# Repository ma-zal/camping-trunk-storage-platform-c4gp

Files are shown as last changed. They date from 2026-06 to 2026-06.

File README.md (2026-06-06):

# Držáky dřevěného profilu pro vestavbu kempovací poličky do automobilu

3D tisknutelné držáky pro upevnění dřevěného profilu, na který se připevní polička.
Držáky jsou navrženy pro snadné nasazení a zajištění proti vysunutí, přičemž využívají existující otvory a oka v zavazadlovém prostoru automobilu.

Pro vůz: Citroen C4 Grand Picasso 2. gen (od 2013)
Jazyk zdrojových dat 3D modelu: OpenSCAD

Rozměry a odvozené hodnoty jsou parametry na začátku každého `.scad` souboru. Sem patří jen účel a záměry, které z kódu nejsou na první pohled zřejmé.

## Přední držák

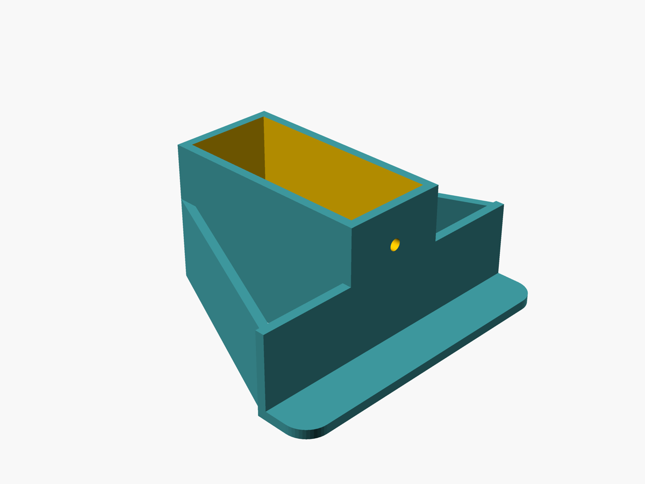
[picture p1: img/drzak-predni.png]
Přední držák


Soubor: `vestavba-drzak-predni.scad`

Účel: nasouvací držák na vodorovný dřevěný profil (vyšší stranou nahoru). Jazýček zapadne do vodorovného úzkém otvoru v automobilu (kterým se vysouvá bezpečnostní pás) a zajistí profil proti vysunutí.

Potřebný dřevěný trám: profil **19 × 43 mm** (užší strana 19 mm, vyšší strana 43 mm nahoru).

Hlavní prvky a záměry:
- Průchozí obdélníkový tunel, otevřený na obou koncích (profil jím prochází).
- Jazýček (háček) na horní straně míří ven od těla a dolů do otvoru. Zaoblený je jen na svých dvou vnějších hranách, strana u těla zůstává ostrá.
- Horní základna rozšiřuje horní plochu do stran a drží profil na středu (proti překlápění). Je zapuštěná do horní stěny tunelu, aby nahoře nevznikala dvojitá tloušťka materiálu.
- Boční výztuhy: jen jedna šikmá deska na každé straně (úhlopříčka od hrany základny k patě tunelu), jejíž vnější hrana lícuje se základnou a nepřečnívá. Záměrně žádný plný ani dutý trojúhelník a žádné členy podél základny či tunelu.
- Volitelný otvor na šroubek skrz horní stěnu tunelu.

`is_poc = true` přepíná na mělčí zkušební variantu (pro rychlejší vytištění).

## Zadní díl - přítlačná podložka

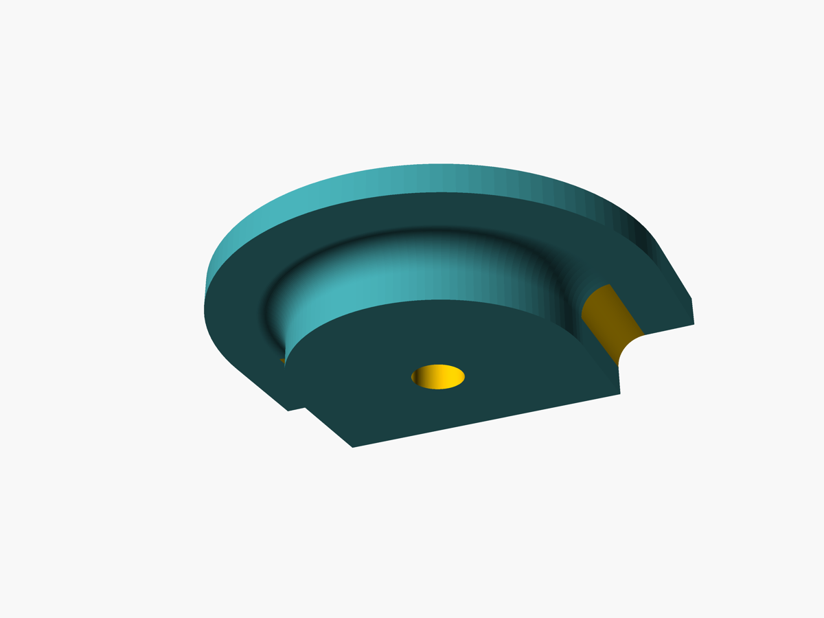
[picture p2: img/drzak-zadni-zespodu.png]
Zadní díl – pohled zespodu na lůžko oka


*Pohled zespodu – na spodní (dosedací) straně je vidět konkávní lůžko (drážka) kopírující prut oka ve tvaru „U".*

Soubor: `vestavba-drzak-zadni.scad`

Princip: Zadní trám leží na okách umístěných na bočních stěnách zavazadlového prostoru. Oka se otočí do vodorovné polohy. Přítlačná podložka se položí na oko a zajistí se šroubkem, který ji přitahuje dolů. Tím přitlačuje oko k trámu a zároveň brání posunutí oka po trámu. Jde tedy o tvarovanou podložku usazenou na oku, jejímž úkolem je oko zafixovat – přitlačit i zaaretovat.

Hlavní prvky a záměry:
- Tvar kopíruje oko ve tvaru „U" (půlkruh + dvě rovné nohy): podložka je z jedné strany kulatá, zbytek rovný.
- Tělo je zespodu tlustý blok se svislou stěnou, nahoře tenký širší lem.
- Lůžko pro prut oka je na spodní straně zaobleno.
- Průchozí otvor pro šroub ve středu, bez zapuštění (kvůli pevnosti).

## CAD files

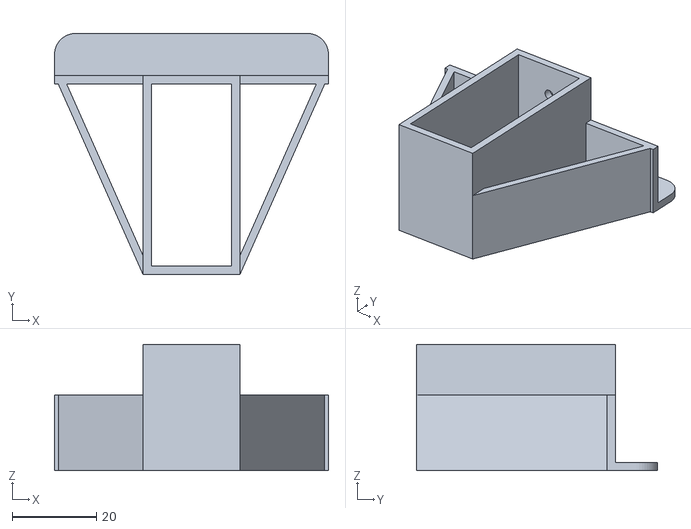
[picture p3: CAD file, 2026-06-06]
vestavba-drzak-predni.stl
65.0 x 57.2 x 30.0

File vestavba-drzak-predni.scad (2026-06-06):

// =====================================================================
//  Nasouvací držák na dřevěný profil 19 x 43 mm
//  ------------------------------------------------------------------
//  Souřadný systém:
//    X = šířka (vodorovně napříč), model je vycentrovaný na X = 0
//    Y = výška (svisle), Y = 0 je dole, profil stojí vyšší stranou nahoru
//    Z = směr nasunutí profilu (tunel je v ose Z průchozí)
// =====================================================================

is_poc = false; // Mene hlubsi varianta, na vyzkouseni

// ---------- Parametry profilu a nasunutí ----------
inner_x = 19;   // vnitřní šířka tunelu (kratší strana profilu + vůle)
inner_y = 43.2;   // vnitřní výška tunelu (delší strana profilu + vůle)
insert_len = is_poc ? 15 : 30;  // délka nasouvací části (hloubka tunelu v ose Z)
wall = 2;         // tloušťka pláště

// ---------- Parametry základny a výztuh ----------
base_w = 65;      // celková šířka základny (shodná se šířkou jazýčku)
base_t = wall;    // tloušťka horní desky základny (zapuštěná do horní stěny tunelu)
rib_depth = is_poc ? 15 : 18;   // vyska bočních výztuh v ose Z (není potřeba celých 20)
rib_wall = wall;  // tloušťka stěny (rámu) duté výztuhy

// ---------- Parametry jazýčku (háčku) ----------
tongue_w = base_w;       // šířka jazýčku
tongue_thick = 2;    // tloušťka stěny jazýčku (v ose Z)
tongue_depth = 10;   // hloubka jazýčku (jak daleko směřuje dolů, osa Y)
tongue_round = 5;  // poloměr zaoblení koncových hran jazýčku

// ---------- Odvozené vnější rozměry ----------
outer_x = inner_x + 2 * wall;   // 25.6 mm
outer_y = inner_y + 2 * wall;   // 49.6 mm

// Jemnost zaoblení
$fn = 48;

// ---------- Výchozí pohled kamery (aby model nebyl mimo záběr) ----------
// Model je v ose Y posunutý nahoru (Y ≈ 0–53), proto kamera míří na jeho
// střed, ne na počátek [0,0,0].
$vpt = [0, 25, 10];     // bod, na který se kamera dívá (střed modelu)
$vpr = [60, 0, 135];    // rotace pohledu (sklon a natočení)
$vpd = 200;            // vzdálenost kamery (zoom)

// =====================================================================
//  Hlavní sestava
// =====================================================================
module drzak() {
    difference() {
        union() {
            // Nasouvací tunel (s průchozím otvorem)
            insert_tunnel();

            // Horní základna + boční výztuhy + jazýček
            top_base();
            side_ribs();
            tongue();
        }

        // Otvor na šroubek v horní (kratší) stěně tunelu
        if (!is_poc) { // pro zkoušku není potřeba, navíc by se špatně vrtalo
            screw_hole();
        }
    }
}

// ---------------------------------------------------------------------
//  Otvor na šroubek – svislý (osa Y) skrz horní stěnu tunelu na straně
//  jazýčku. Vystředěný na X = 0, v ose Z přibližně 10 mm od zadní hrany
//  tunelu (Z = 20). Průměr 2.5 mm.
// ---------------------------------------------------------------------
module screw_hole() {
    screw_d = 2.5;
    screw_z = insert_len - 8;          // poloha v ose Z (hloubka nasunutí)

    translate([0, outer_y + 0.1, screw_z])
        rotate([90, 0, 0])     // válec z osy Z do osy Y (shora dolů)
            cylinder(h = 2 * wall + 0.2, d = screw_d);
}

// ---------------------------------------------------------------------
//  Nasouvací tunel – obdélníkový průchozí tunel otevřený na obou stranách
// ---------------------------------------------------------------------
module insert_tunnel() {
    difference() {
        // Vnější těleso, vycentrované na X = 0
        translate([-outer_x / 2, 0, 0])
            cube([outer_x, outer_y, insert_len]);

        // Vnitřní průchozí otvor (přesah 0.1 na obou koncích kvůli čistému řezu)
        translate([-inner_x / 2, wall, -0.1])
            cube([inner_x, inner_y, insert_len + 0.2]);
    }
}

// ---------------------------------------------------------------------
//  Horní základna – plochá deska 60 mm široká přes horní stranu tunelu.
//  Je zapuštěná do horní stěny tunelu (horní plocha v rovině outer_y),
//  takže nad tunelem nevzniká dvojitá tloušťka – přes šířku tunelu se
//  jen překryje s jeho stěnou, navíc rozšiřuje horní plochu do stran.
// ---------------------------------------------------------------------
module top_base() {
    translate([-base_w / 2, outer_y - base_t, 0])
        cube([base_w, base_t, rib_depth]);
}

// ---------------------------------------------------------------------
//  Boční výztuhy – jedna šikmá deska (úhlopříčka původního trojúhelníku)
//  napříč od hrany základny dolů k patě tunelu. Členy podél základny ani
//  podél tunelu nejsou potřeba. Vnější hrana desky lícuje s úhlopříčkou
//  (roh základny → pata tunelu), tloušťka jde dovnitř k tunelu, takže
//  deska nepřečnívá za základnu. Tloušťka rib_wall, hloubka rib_depth.
// ---------------------------------------------------------------------
module side_ribs() {
    p_top = [base_w / 2,  outer_y];   // horní vnější roh (hrana základny)
    p_bot = [outer_x / 2, 0];         // dolní vnější roh (pata tunelu)

    for (mx = [1, -1]) {              // pravá (+X) a levá (-X) strana
        scale([mx, 1, 1])
        linear_extrude(height = rib_depth)
            polygon(points = [
                p_top,                  // horní vnější (roh základny)
                p_bot,                  // dolní vnější (pata tunelu)
                p_bot - [rib_wall, 0],  // dolní vnitřní (k tunelu)
                p_top - [rib_wall, 0],  // horní vnitřní
            ]);
    }
}

// ---------------------------------------------------------------------
//  Jazýček (háček) – visí z předního přesahu základny směrem dolů,
//  ven od modelu (mimo těleso tunelu). Šířka 60, tloušťka stěny 4,
//  hloubka 10. Zaoblené jsou koncové (boční) hrany, ne podélné.
//  Zapadne do vodorovného otvoru a zajistí profil proti vysunutí.
// ---------------------------------------------------------------------
module tongue() {
    // Jazýček vychází z horní plochy (rovina outer_y)
    y_bottom = outer_y;

    // Profil leží v rovině šířka (X) × hloubka (Y) a vytlačí se v ose Z
    // (tloušťka). Tím se zaoblí koncové hrany běžící napříč tloušťkou.
    translate([0, y_bottom, 0])
        linear_extrude(height = tongue_thick)
            tongue_profile();
}

// 2D profil jazýčku v rovině (X = šířka, Y = hloubka).
// Zaoblené jsou jen dva vnější rohy (hrany mířící ven, y = d);
// strana přiléhající k držáku (y = 0) zůstává ostrá.
module tongue_profile() {
    w = tongue_w;
    d = tongue_depth;
    r = tongue_round;

    hull() {
        // tělo s ostrou hranou u držáku
        translate([-w / 2, 0]) square([w, d - r]);
        // zaoblené vnější rohy
        translate([-w / 2 + r, d - r]) circle(r = r);
        translate([ w / 2 - r, d - r]) circle(r = r);
    }
}

// =====================================================================
//  Render
// =====================================================================
drzak();

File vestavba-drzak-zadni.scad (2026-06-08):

// =====================================================================
//  Zadní držák – kruhová podložka na oko (přitlačení oka k trámu)
//  ------------------------------------------------------------------
//  Princip (viz README): zadní trám leží na okách na bočních stěnách
//  kufru. Tato podložka se položí na oko a přišroubuje se šroubem skrz
//  střed. Tím přitlačí prut oka k trámu a zároveň brání jeho posuvu –
//  prut oka sedí v lůžku na spodní straně podložky.
//
//  Tvar oka je U (půlkruh + dvě rovné nohy), proto lůžko kopíruje U
//  a samotná podložka je „půl kulatá, zbytek rovný". Tělo je tvořené
//  zespodu: tlustý blok se svislou stěnou + nahoře tenký širší lem.
//  Lůžko prutu NENÍ odebraná drážka – je to konkávní 90° zaoblení (R3)
//  PŘIDANÉ do rohu (stěna ↔ spodek lemu). Stěna pod lůžkem je proto
//  svislá a u dna ostrá, žádný obloukový převis.
//
//  Souřadný systém:
//    Z = tloušťka podložky, Z = 0 je dolní (dosedací) plocha
//    Lůžko pro prut je při spodní ploše (prut sedí zdola, vně stěny)
//    U se otevírá ve směru +Y, kulatá část je na straně -Y, střed na [0,0]
// =====================================================================

// ---------- Hlavní rozměry podložky ----------
thickness       = 9;    // celková tloušťka plného bloku, vcetne tloustky rozsirene casti.
shelf_thickness = 3;    // tloušťka rozsirene casti (lem za drážkou)

// ---------- Parametry oka a jeho drážky ----------
eye_rod_d   = 6;    // průměr prutu oka ("6mm OKO")
eye_pitch_inner_d = 29.4; // průměr vnitřní části U – osa prutu
leg_len     = 8;   // délka rovných nohou U (jak daleko pokračují rovně). Max 15mm.

eye_pitch_d = eye_pitch_inner_d + eye_rod_d;   // průměr kulaté části U – osa prutu

// ---------- Šířky lemu ----------
inner_margin = 0;   // jemný posun svislé stěny (0 = přesně na vnitřní tečně prutu)

// ---------- Otvor na šroub ----------
screw_d     = 5.2;    // průchozí otvor pro šroub skrz střed
screw_offset = 10;  // Posun otvoru oproti středu víc ke špičce

// ---------- Odvozené hodnoty ----------
groove_r   = eye_rod_d / 2;          // poloměr lůžka = 3 mm (rádius z nákresu)
pitch_r    = eye_pitch_d / 2;        // poloměr osy prutu oka = 18 mm
full_r     = pitch_r - groove_r + inner_margin;  // svislá stěna na vnitřní tečně prutu
outer_r    = 46 / 2;             // vnější okraj lemu (polomer od stredu osy)
corner_z   = thickness - shelf_thickness;        // výška spodku lemu = výška rohu (lůžka)

eps = 0.01; // malý posun pro zajištění správného pořadí operací (rozdíl mezi "vnitřní" a "vnější" částí)

// Jemnost zaoblení
$fn = 128;

// ---------- Výchozí pohled kamery ----------
$vpt = [0, 8, 3];
$vpr = [110, 0, 25];
$vpd = 160;

// =====================================================================
//  Hlavní sestava
// =====================================================================
module podlozka() {
    difference() {
        union() {
            // tenký horní lem (širší), na opačné straně než lůžko
            translate([0, 0, corner_z])
                ushape_slab(outer_r, shelf_thickness, leg_len);
            // tlustý blok se svislou stěnou (vnitřní část)
            ushape_slab(full_r, thickness, leg_len);
            // aditivní zaoblené lůžko prutu v rohu (U: oblouk + nohy)
            eye_fillet();
        }
        screw_hole();       // průchozí otvor pro šroub
    }
}

// ---------------------------------------------------------------------
//  Tvar „U" jako plný blok dané tloušťky: půlkruh (poloměr r) na straně
//  -Y + obdélníková část pokračující rovně do +Y o délce L.
// ---------------------------------------------------------------------
module ushape_slab(r, t, L) {
    union() {
        // kulatá půlka (Y <= 0)
        intersection() {
            cylinder(r = r, h = t);
            translate([-r - 1, -2 * r - 1, -1])
                cube([2 * r + 2, 2 * r + 1, t + 2]);
        }
        // rovná část (Y = 0 .. L)
        translate([-r, 0, 0]) cube([2 * r, L, t]);
    }
}

// ---------------------------------------------------------------------
//  Lůžko prutu oka – kopíruje U: konkávní 90° zaoblení (R = groove_r)
//  PŘIDANÉ do rohu, kde se svislá stěna tlustého bloku (poloměr full_r)
//  potkává se spodkem horního lemu (výška corner_z). Prut sedí vně té
//  stěny, spodkem v rovině Z = 0; zaoblení vystředěné na osu prutu tvoří
//  jeho lůžko. Stěna pod lůžkem je svislá a u dna ostrá (nic se neodebírá).
// ---------------------------------------------------------------------
module eye_fillet() {
    // kulatá půlka lůžka (Y <= 0)
    rotate([0, 0, 180])
        rotate_extrude(angle = 180)
            fillet_profile();

    // rovné nohy podél obou stran U
    for (mx = [1, -1])
        scale([mx, 1, 1]) fillet_leg();
}

// 2D profil zaoblení rohu (x = radiála, y = výška): čtverec R×R v rohu
// mínus kružnice R vystředěná na osu prutu → konkávní čtvrtkruhové lůžko.
module fillet_profile() {
    difference() {
        // levá hrana posunutá o eps do středu (−x) → překryv s válcovou stěnou
        // (jinak se profil stěny jen tečně dotýká = čára nulové tloušťky)
        translate([full_r - eps, corner_z - groove_r]) square([groove_r + eps, groove_r]);
        translate([full_r + groove_r, corner_z - groove_r]) circle(r = groove_r);
    }
}

// 3D ekvivalent profilu pro rovnou nohu (+X strana): kvádr v rohu mínus
// válec (osa podél Y) = vytlačený fillet_profile. Přesah 0.1 na obou koncích.
module fillet_leg() {
    difference() {
        translate([full_r, -eps, corner_z - groove_r])
            cube([groove_r, leg_len + 2 * eps, groove_r]);
        translate([full_r + groove_r, -2 * eps, corner_z - groove_r])
            rotate([-90, 0, 0])
                cylinder(r = groove_r, h = leg_len + 4 * eps);
    }
}

// ---------------------------------------------------------------------
//  Průchozí otvor pro šroub ve středu kulaté části
//  Bez zaoblení - nepoužito pro maximální pevnost
// ---------------------------------------------------------------------
module screw_hole() {
    translate([0, -screw_offset, -eps])
        cylinder(h = thickness + 2 * eps, d = screw_d);
}


// =====================================================================
//  Render
// =====================================================================
podlozka();

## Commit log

2026-06-01 draft - chybne jazycek, maly support
    [vestavba-drzak.scad]
2026-06-01 ok - velke podpory jako duty trojuhelnik
    [vestavba-drzak.scad]
2026-06-01 ok - podpory jako jedna linie
    [vestavba-drzak.scad]
2026-06-01 zaobleni tuned
    [vestavba-drzak.scad]
2026-06-01 mensi verze
    [vestavba-drzak.scad]
2026-06-06 final predni drzak
    [vestavba-drzak.scad, vestavba-drzak.stl]
2026-06-06 podlozka zadni
    [vestavba-drzak-zadni.scad]
2026-06-08 zadni drzak - rc1 verze
    [vestavba-drzak-zadni.scad]
